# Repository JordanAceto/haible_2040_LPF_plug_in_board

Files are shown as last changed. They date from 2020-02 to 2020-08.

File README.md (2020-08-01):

# NOTE: development of all VCF plug-in boards has been moved here https://github.com/JordanAceto/VCF_plug_in_boards
### This repo will no longer be updated. Follow the above link for the most current files.

# Discrete SSM2040 LPF Plug-In Board 

Small low pass filter PCB, designed to plug into a larger motherboard. This discrete SSM2040 filter implementation is based on notes from the late Jurgen Haible. Thank you for all your wonderful contributions Jurgen.

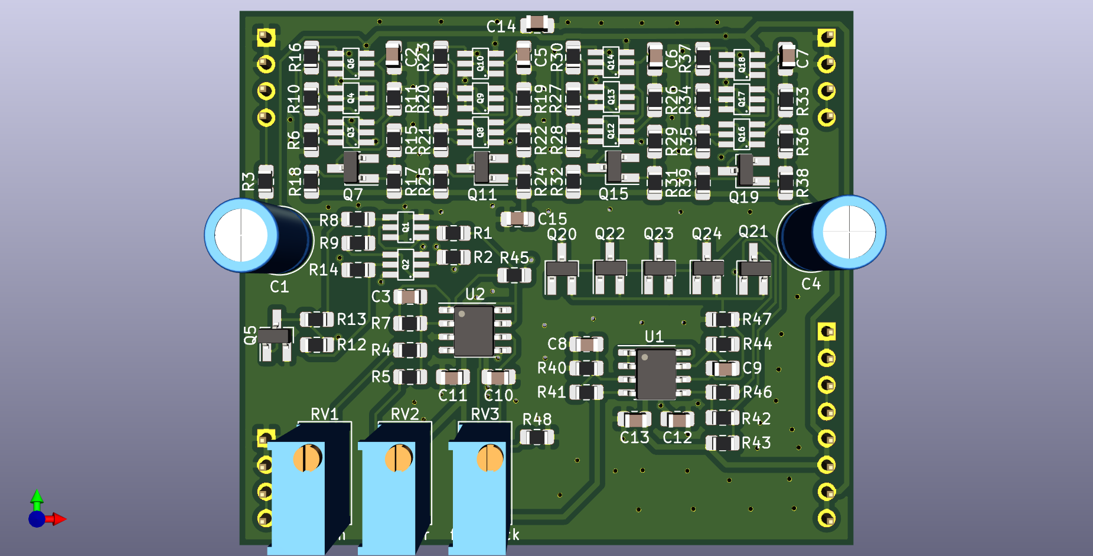
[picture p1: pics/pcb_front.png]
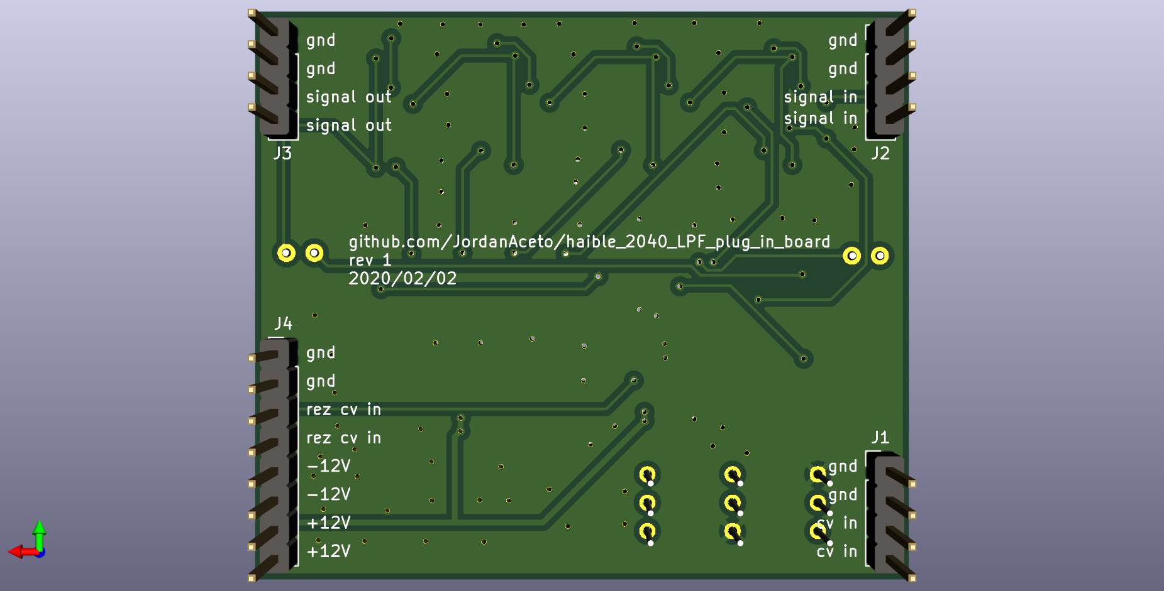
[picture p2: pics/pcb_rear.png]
 

## Details

Four pole LPF with Q compensation. This PCB includes the audio path and CV inputs for frequency and feedback, but does not include any modulation sources.

The intended use for this board is to plug in to a larger motherboard which contains slots for two of these plug-in boards, as well as modulation sources, panel controls, and input/output routing. This motherboard could accept different filter boards sharing this footprint and header layout, for realizing stereo effects of various flavors.

## Inputs

-Audio in: dry audio input to be filtered.

-Frequency CV in: 0 volts to +2.048 volts, higher voltage = higher sweep.

-Feedback CV in: 0 volts to +2.048 volts, higher voltage = more feedback.

## Outputs

-Audio out: filtered audio output.

## Power Supply Requirements

A bipolar 12 volt power supply is required. This will typically come from the motherboard.

## Calibration

-RV1 (depth trim): trims the depth of incoming frequency CV signals. Turn CW for greater depth and CCW for less depth. Adjust to taste.

-RV2 (center trim): trims the center frequency of the filter. Turn CW for higher center frequency and CCW for lower center frequency. Adjust to taste.

-RV3 (feedback trim): trims the maximum amount of feedback. Turn CW for more maximum feedback and CCW for less maximum feedback. Exercise caution when adjusting this, as extreme settings can result in loud oscillations which could damage your ears or speakers if you are monitoring the sound with a loud amplifier. If you set this trimmer to be right on the edge of oscillation when about +2 volts is applied to the feedback CV input then make sure to sweep the frequency through its entire range, as a setting that doesn't squeal at certain frequency settings may squeal at other settings.

## Parts Ordering
The BOM has a link to a Mouser project.

Gerbers can be generated from the kicad_docs.

## License
CC by 4.0

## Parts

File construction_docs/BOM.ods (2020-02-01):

Reference | Quantity | Value | Footprint | Unit Price | Total Price | Product Page
Mouser Parts
C1 C5 | 2 | 10uF | Radial_D6.3mm_H11.0mm_P2.50mm | $0.45 | $0.90 | https://www.mouser.com/ProductDetail/Nichicon/UES1V100MEM
C12 C13 C14 C15 C10 C11 | 6 | 100nF | 0805 | $0.10 | $0.60 | https://www.mouser.com/ProductDetail/KEMET/C0805C104M5RACTU
C2 | 1 | 22uF | 0805 | $0.52 | $0.52 | https://www.mouser.com/ProductDetail/Taiyo-Yuden/TMK212BBJ226MG-TT
C3 | 1 | 470pF | 0805 | $0.14 | $0.14 | https://www.mouser.com/ProductDetail/Yageo/CC0805JRNPO9BN471?qs=sGAEpiMZZMs0AnBnWHyRQMMzfhmH8IQXUBKdtHCIPbI%3D
C4 C7 C8 C9 | 4 | 1nF | 0805 | $0.28 | $1.12 | https://www.mouser.com/ProductDetail/Yageo/CC0805FRNPO9BN102
C6 | 1 | 2n2 | 0805 | $0.27 | $0.27 | https://www.mouser.com/ProductDetail/Yageo/CC0805JKNPO9BN222?qs=sGAEpiMZZMs0AnBnWHyRQMMzfhmH8IQXzJfNxPelwGg%3D
J1 J2 J3 J4 | 1 | breakaway headers | 2.54mm:PinHeader | $2.78 | $2.78 | https://www.mouser.com/ProductDetail/TE-Connectivity/4-103185-0
Q3 Q8 Q12 Q16 Q2 Q1 | 6 | BCM857DS | SOT457 | $0.41 | $2.46 | https://www.mouser.com/ProductDetail/Nexperia/BCM857DS135?qs=sGAEpiMZZMvKM5ialpXrmrzXp%252BgF%2FDi0
Q4 Q6 Q9 Q10 Q13 Q14 Q17 Q18 | 8 | BCM847DS | SOT457 | $0.41 | $3.28 | https://www.mouser.com/ProductDetail/Nexperia/BCM847DS115
Q7 Q23 Q22 Q21 Q20 Q24 Q5 Q11 Q15 Q19 | 10 | BC847 | SOT-23 | $0.13 | $1.30 | https://www.mouser.com/ProductDetail/Nexperia/BC847C215
R16 | 1 | 20k | 0805 | $0.10 | $0.10 | https://www.mouser.com/ProductDetail/Bourns/CR0805-FX-2002ELF
R17 | 1 | 100 | 0805 | $0.10 | $0.10 | https://www.mouser.com/ProductDetail/Bourns/CR0805-FX-1000ELF
R18 R11 R30 R37 R44 | 5 | 120k | 0805 | $0.10 | $0.50 | https://www.mouser.com/ProductDetail/Bourns/CR0805-FX-1203ELF
R19 R12 R31 R28 R38 R35 R45 R42 | 8 | 10k | 0805 | $0.10 | $0.80 | https://www.mouser.com/ProductDetail/Bourns/CR0805-FX-1002ELF
R2 R14 R26 R1 | 4 | 1k | 0805 | $0.10 | $0.40 | https://www.mouser.com/ProductDetail/Bourns/CR0805-FX-1001ELF
R20 | 1 | 180k | 0805 | $0.10 | $0.10 | https://www.mouser.com/ProductDetail/Bourns/CR0805-FX-1803ELF
R21 R15 R10 R32 R39 R46 | 6 | 12k | 0805 | $0.10 | $0.60 | https://www.mouser.com/ProductDetail/Bourns/CR0805-FX-1202ELF
R22 R33 R40 R47 | 4 | 1k2 | 0805 | $0.10 | $0.40 | https://www.mouser.com/ProductDetail/Bourns/CR0805-FX-1201ELF
R23 | 1 | 2k2 | 0805 | $0.10 | $0.10 | https://www.mouser.com/ProductDetail/Bourns/CR0805-FX-2201ELF
R27 R4 | 2 | 100k | 0805 | $0.10 | $0.20 | https://www.mouser.com/ProductDetail/Bourns/CR0805-FX-1003ELF
R3 R24 | 2 | 51k | 0805 | $0.10 | $0.20 | https://www.mouser.com/ProductDetail/Bourns/CR0805-FX-5102ELF
R48 | 1 | 27k | 0805 | $0.10 | $0.10 | https://www.mouser.com/ProductDetail/Bourns/CR0805-FX-2702ELF
R5 R7 | 2 | 560k | 0805 | $0.10 | $0.20 | https://www.mouser.com/ProductDetail/Bourns/CR0805-FX-5603ELF
R6 R13 R25 R29 R34 R36 R41 R43 | 8 | 220 | 0805 | $0.10 | $0.80 | https://www.mouser.com/ProductDetail/Bourns/CR0805-FX-2200ELF
R8 | 1 | 3k3 | 0805 | $0.10 | $0.10 | https://www.mouser.com/ProductDetail/Bourns/CR0805-FX-3301ELF
R9 | 1 | 15k | 0805 | $0.10 | $0.10 | https://www.mouser.com/ProductDetail/Bourns/CR0805-FX-1502ELF
RV1 | 1 | 10k | Bourns_3269W | $4.83 | $4.83 | https://www.mouser.com/ProductDetail/Bourns/3269W-1-103LF?qs=sGAEpiMZZMvygUB3GLcD7lKKmqkeksZmGot4dXELruo%3D
RV2 RV3 | 2 | 100k | Bourns_3269W | $4.83 | $9.66 | https://www.mouser.com/ProductDetail/Bourns/3269W-1-104LF?qs=sGAEpiMZZMvygUB3GLcD7iPUMwpiXMBsQtXtzdbyTwg%3D
U1 U2 | 2 | TL072 | SOIC-8 | $0.59 | $1.18 | https://www.mouser.com/ProductDetail/Texas-Instruments/TL072CDR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
 |  |  | Total |  | $33.84
 |  |  | Link to Mouser project |  |  | https://www.mouser.com/ProjectManager/ProjectDetail.aspx?AccessID=2b5f0e1beb

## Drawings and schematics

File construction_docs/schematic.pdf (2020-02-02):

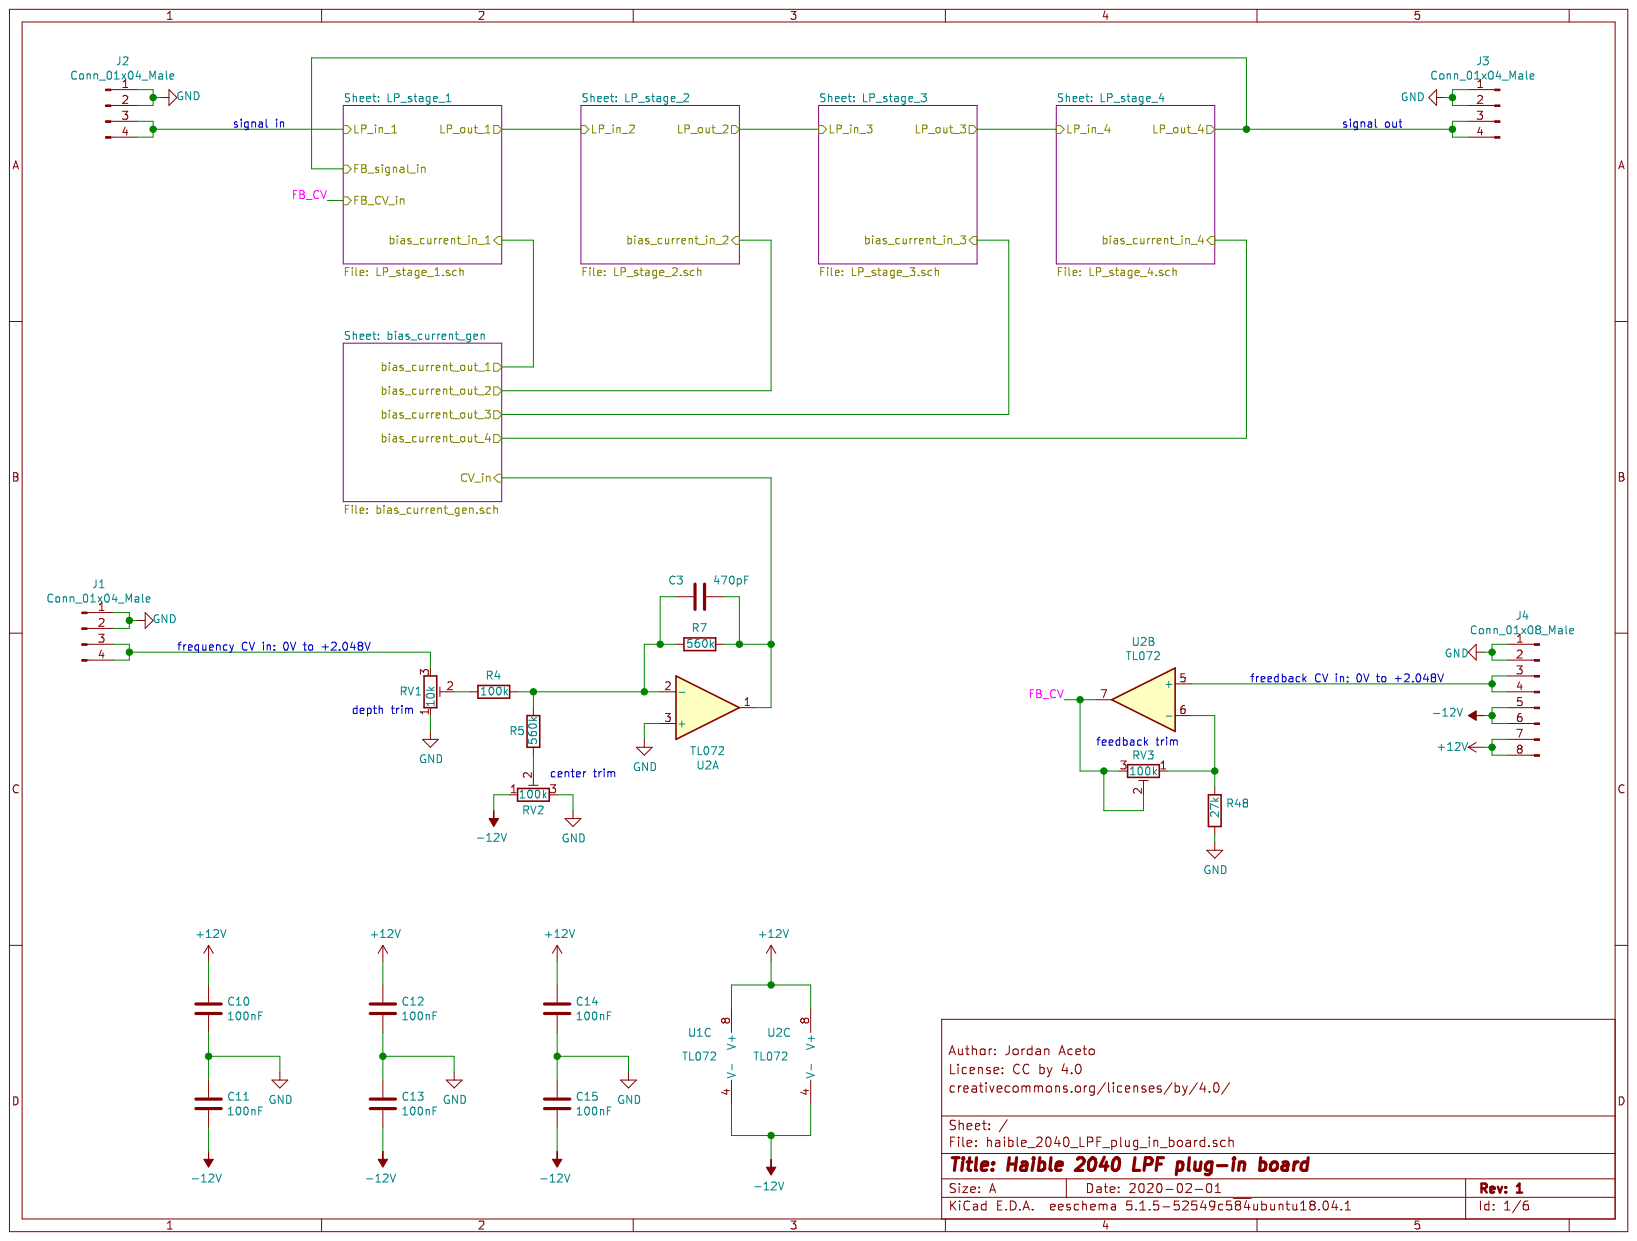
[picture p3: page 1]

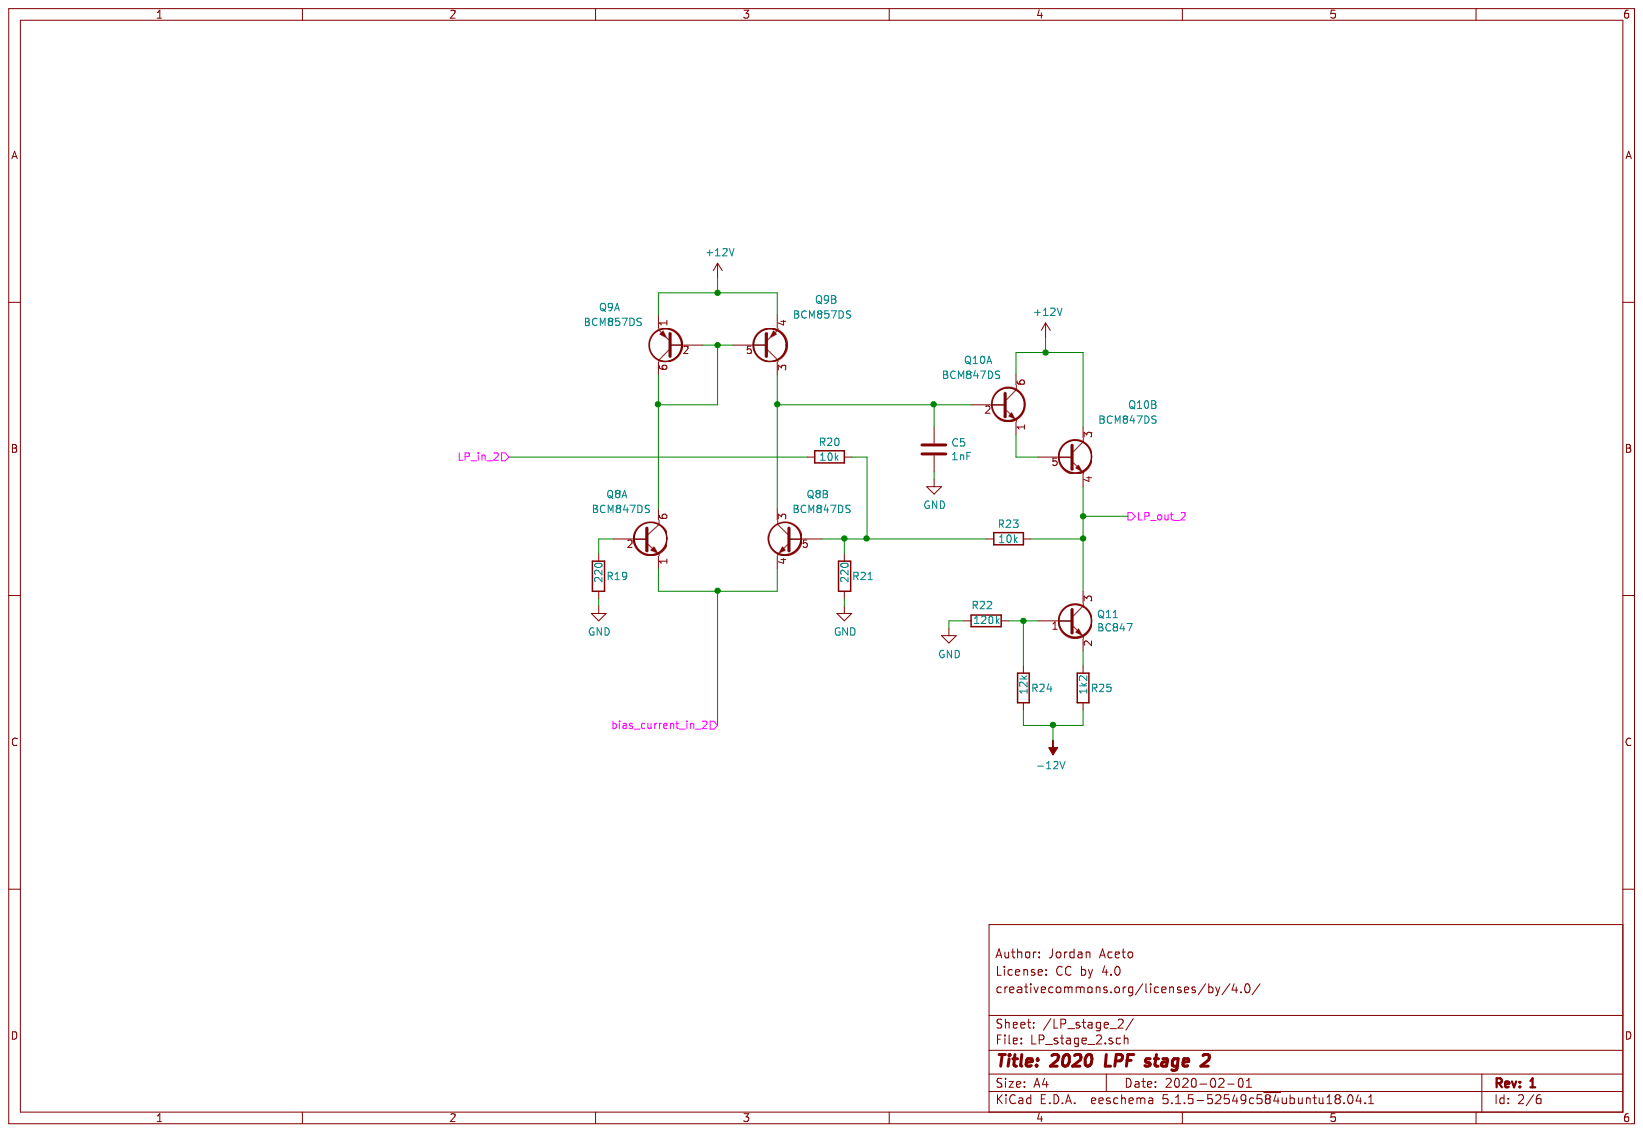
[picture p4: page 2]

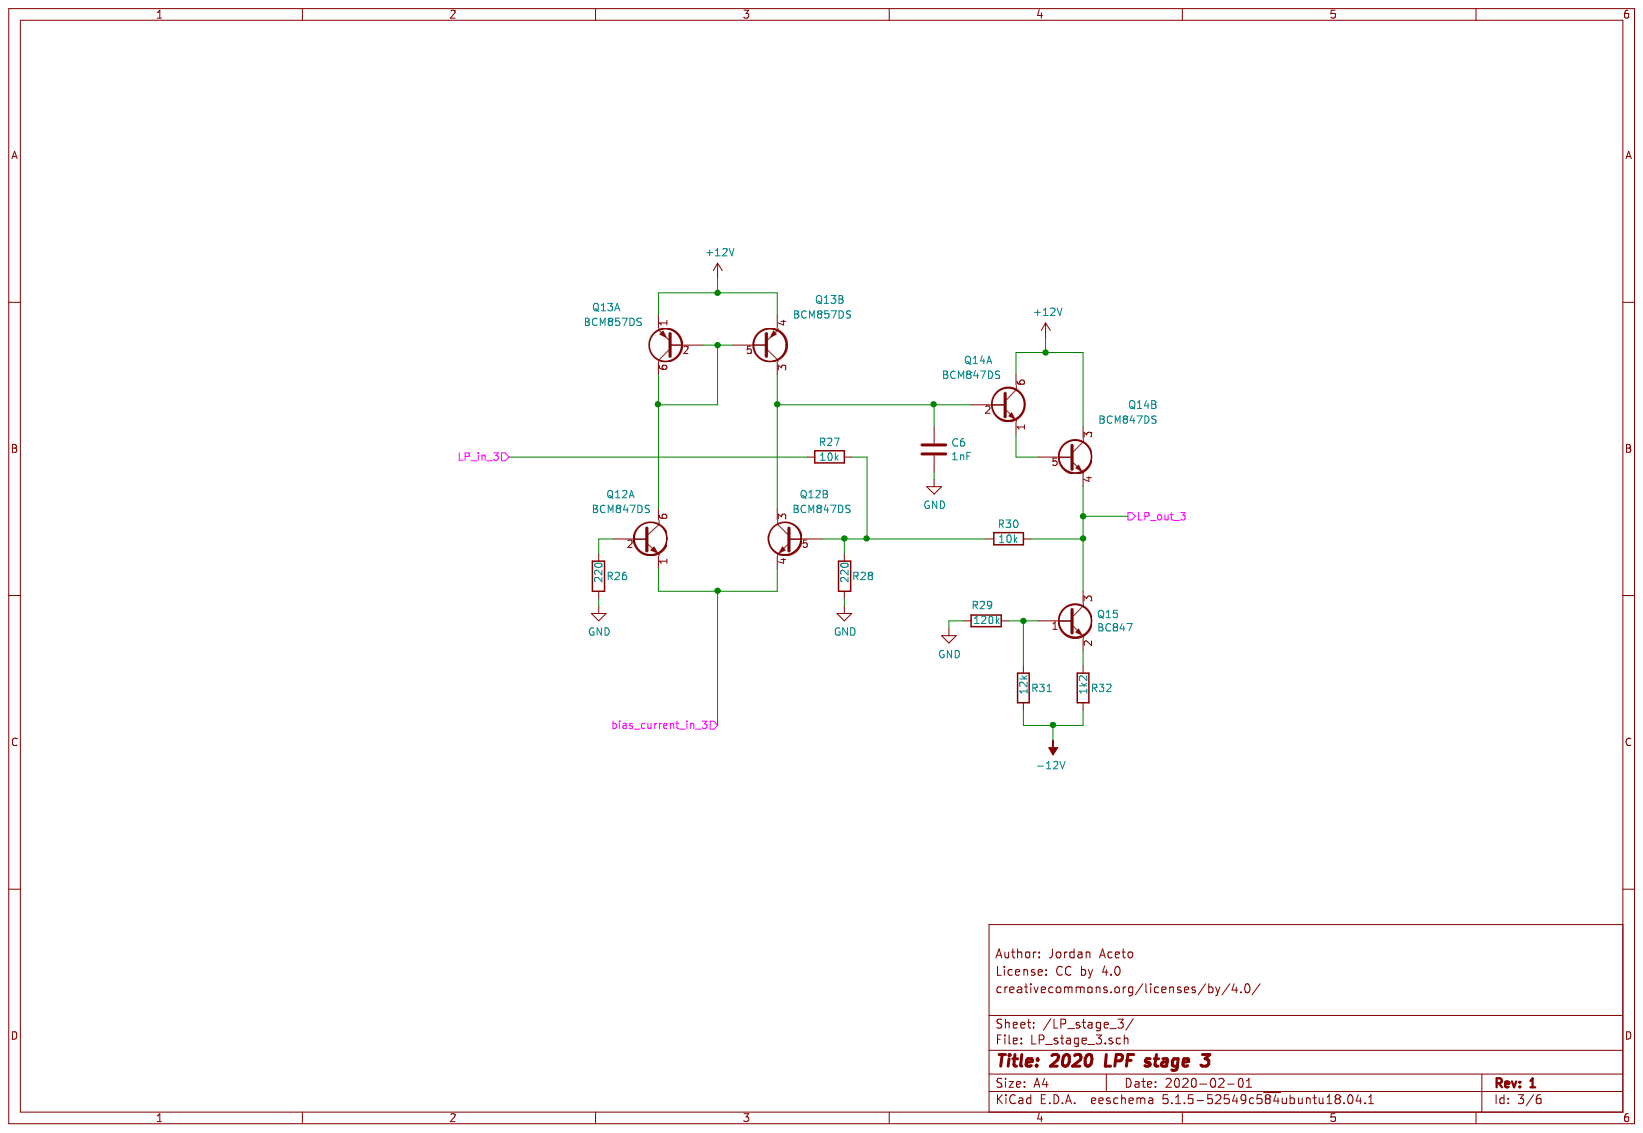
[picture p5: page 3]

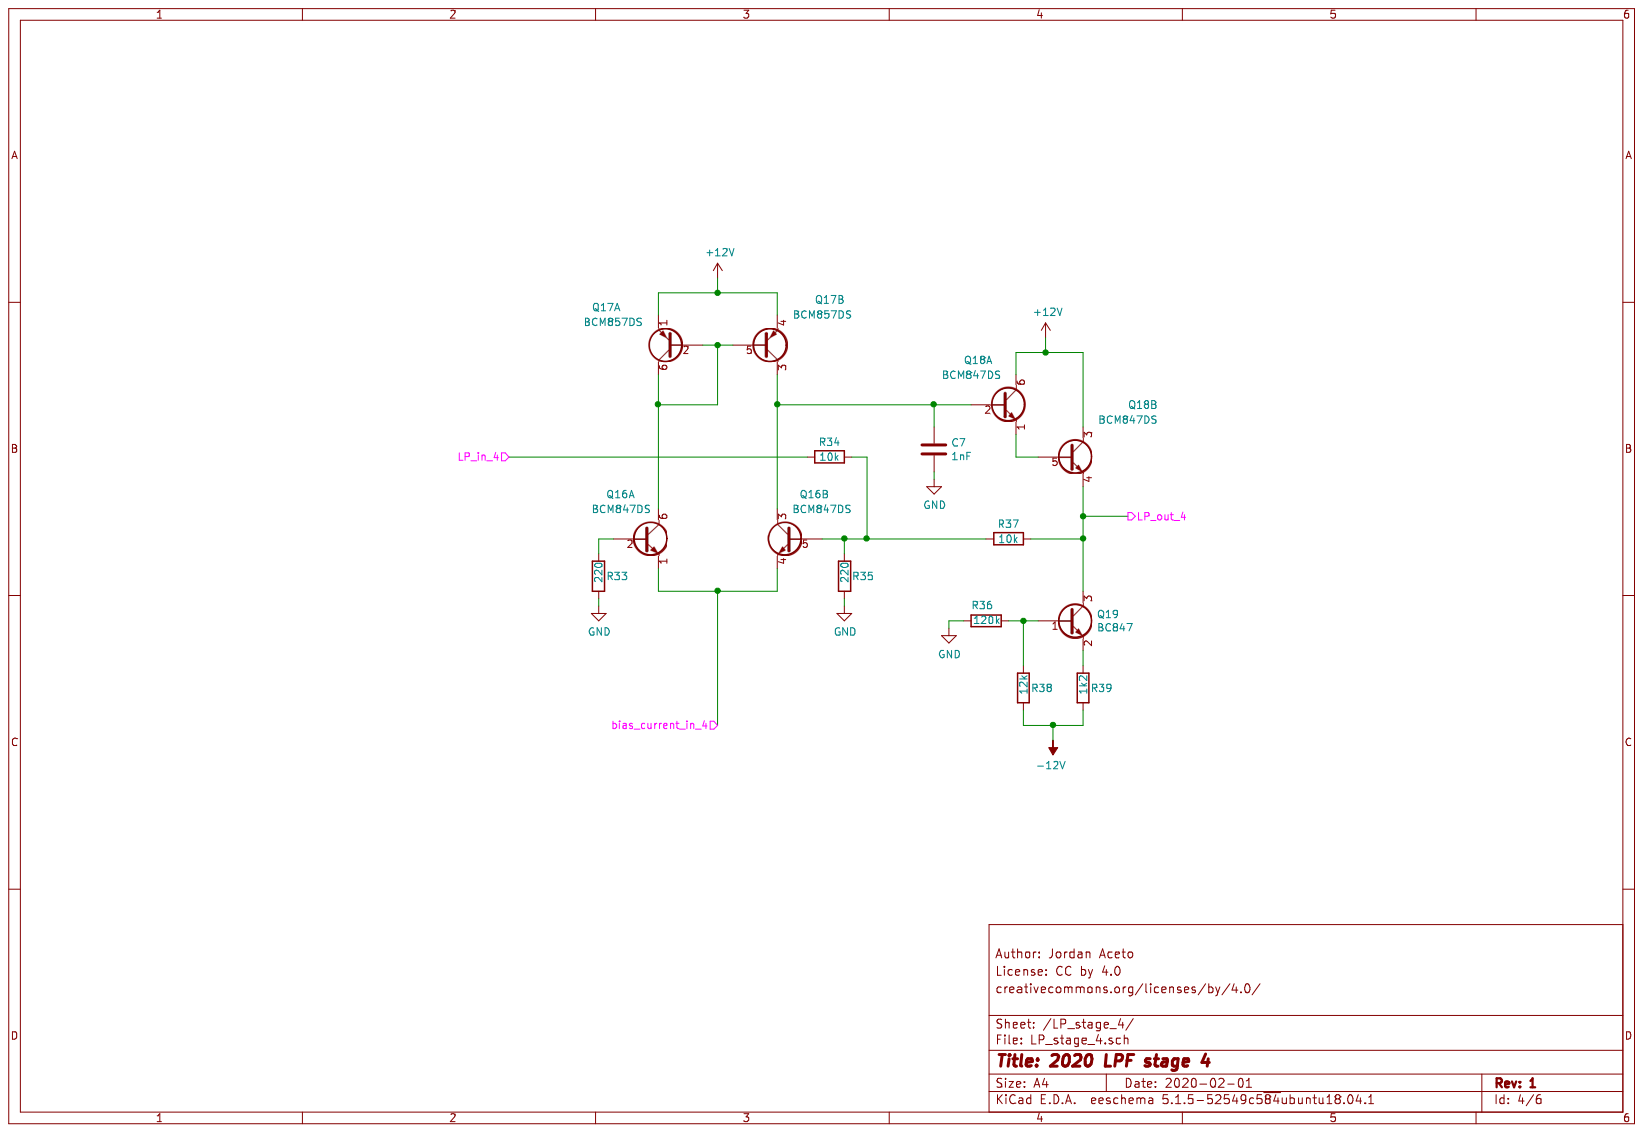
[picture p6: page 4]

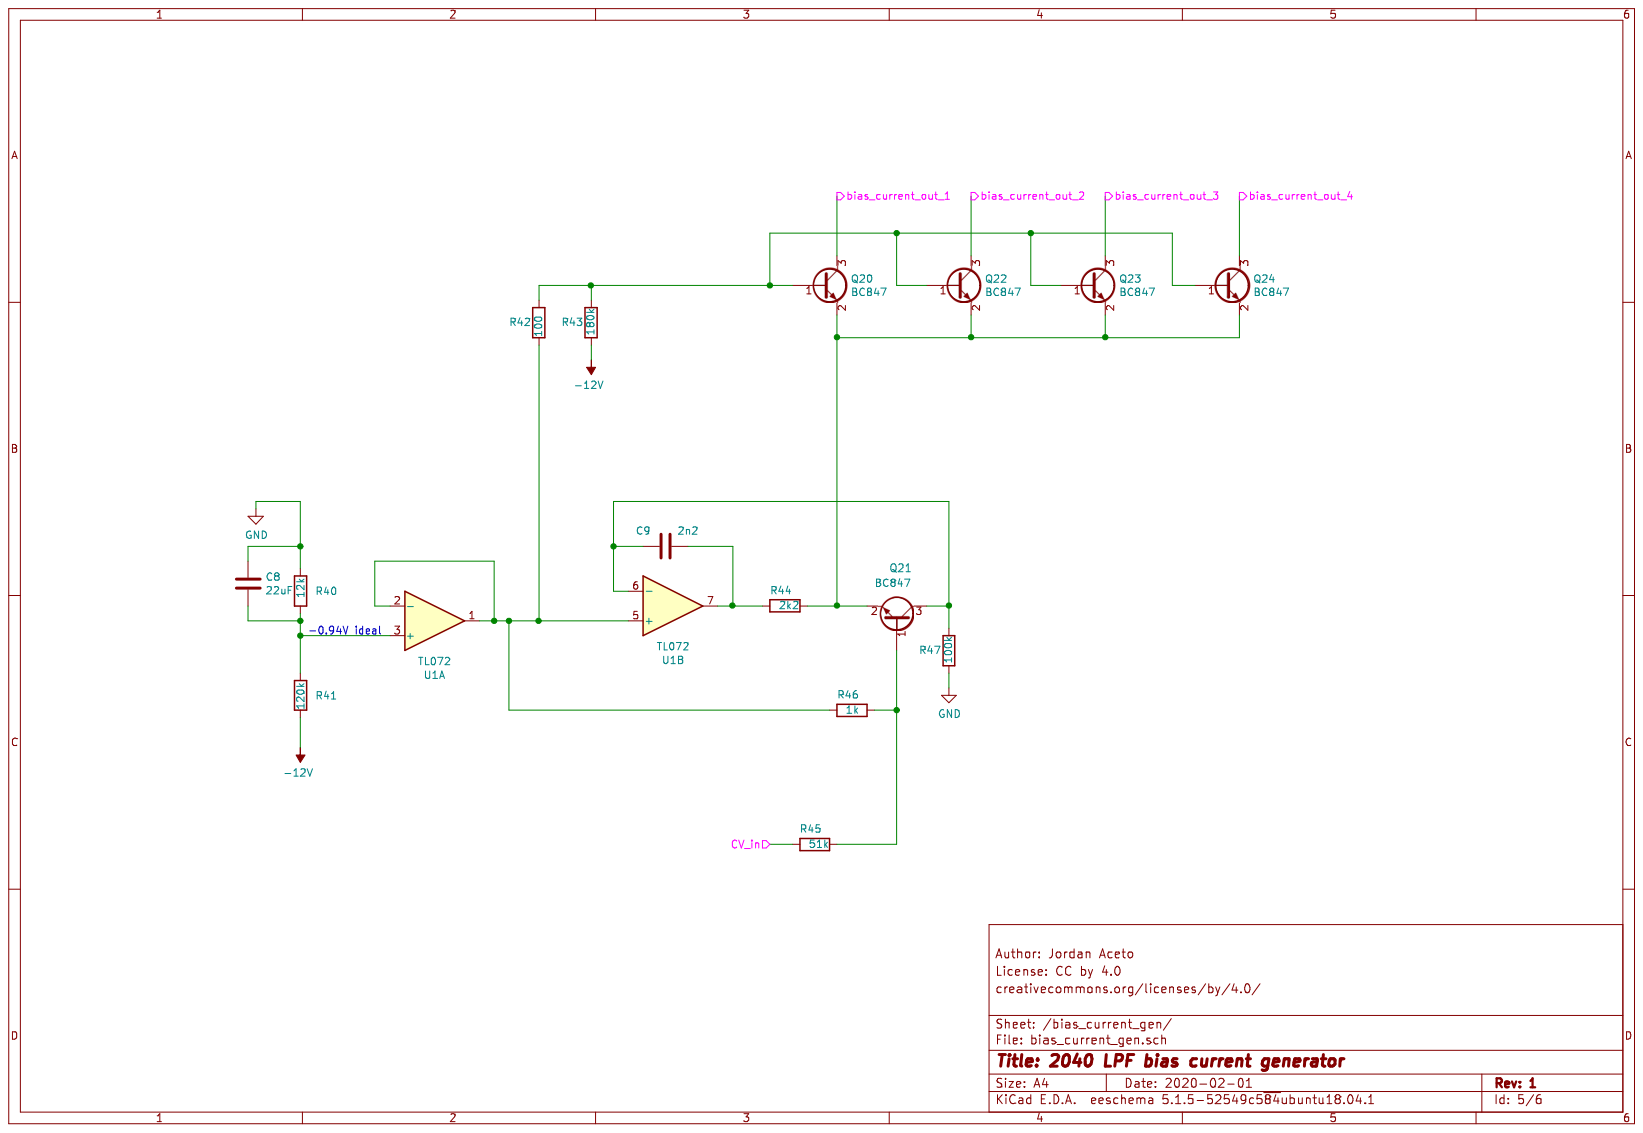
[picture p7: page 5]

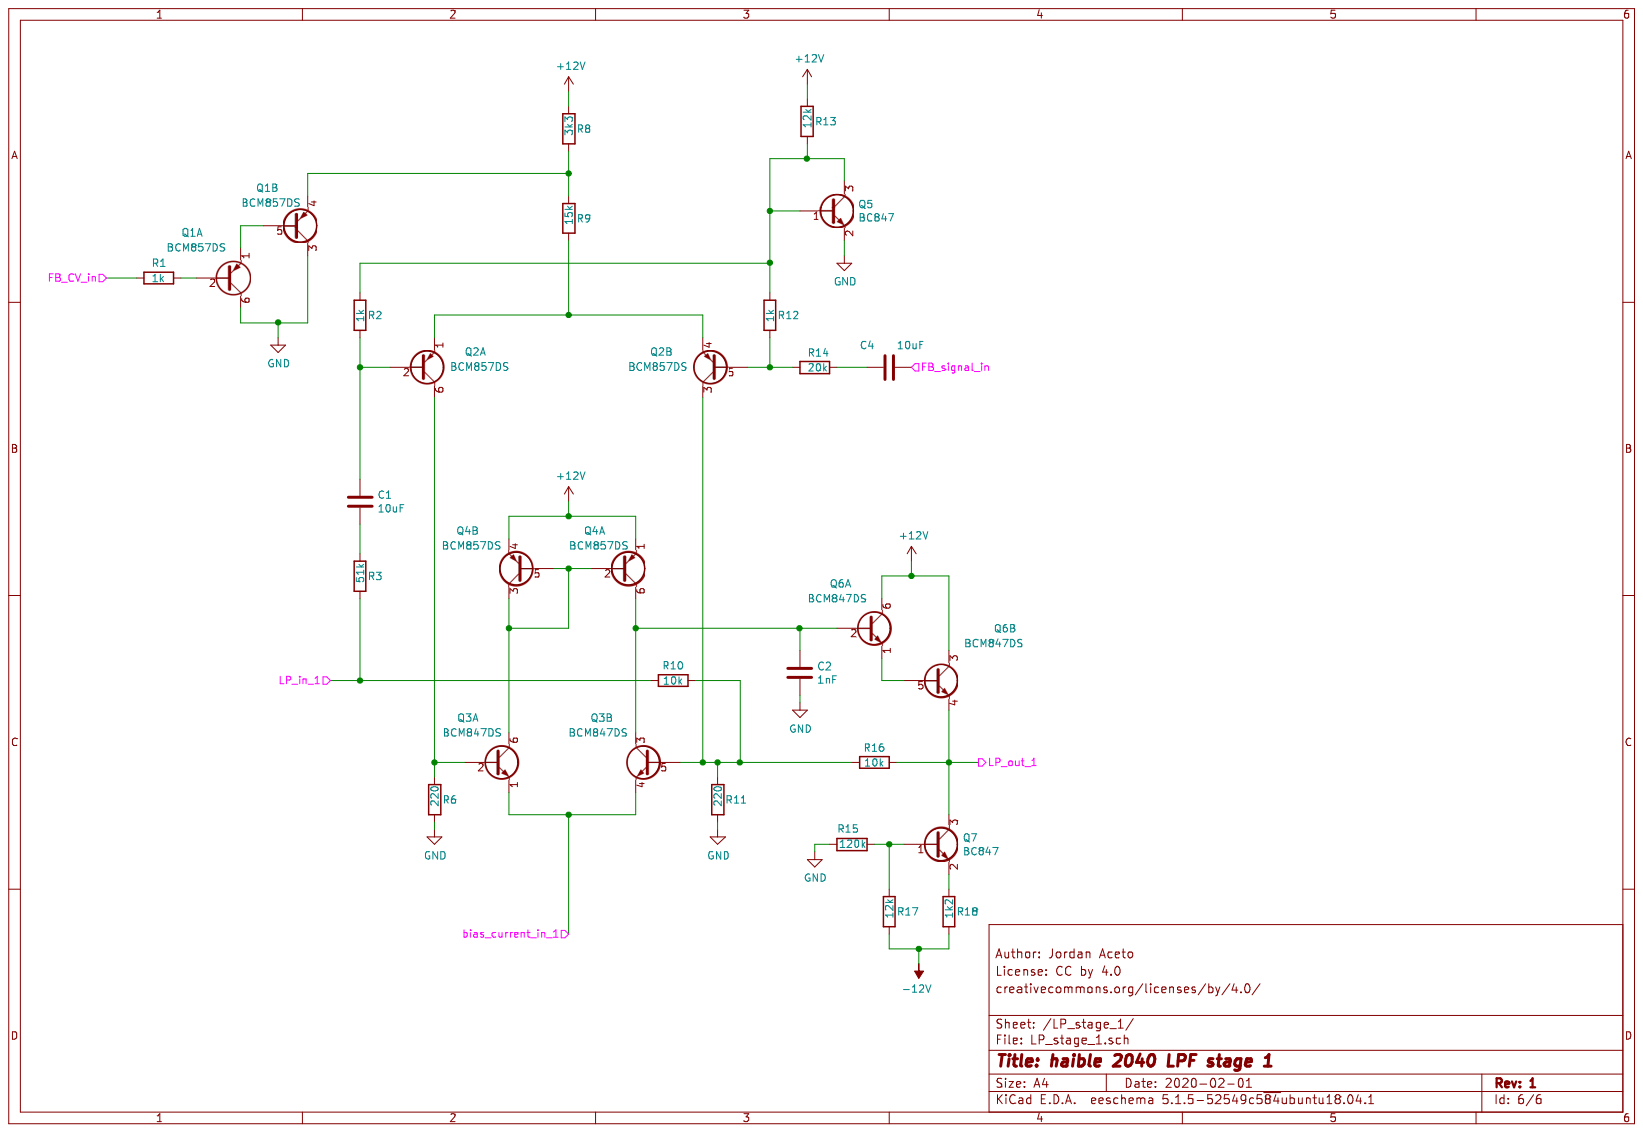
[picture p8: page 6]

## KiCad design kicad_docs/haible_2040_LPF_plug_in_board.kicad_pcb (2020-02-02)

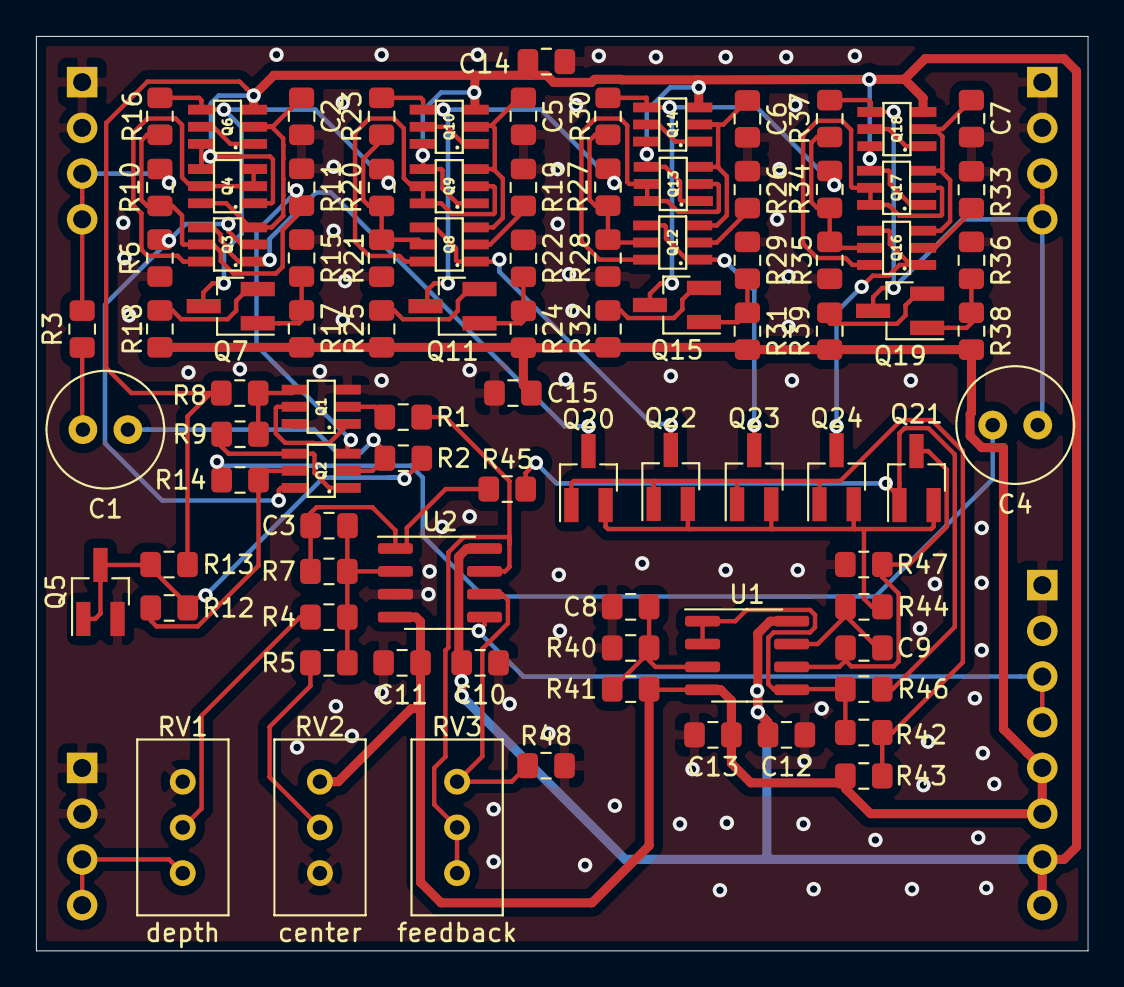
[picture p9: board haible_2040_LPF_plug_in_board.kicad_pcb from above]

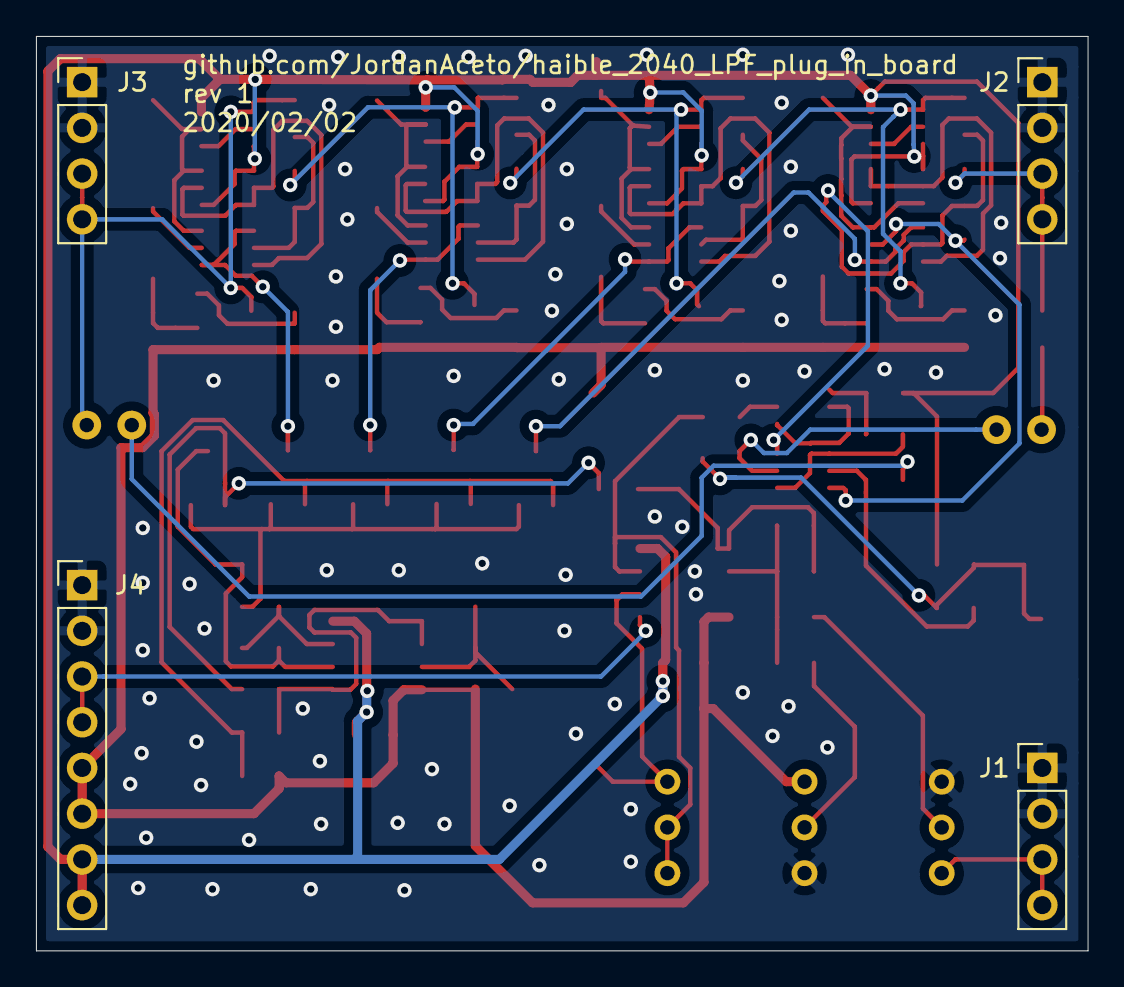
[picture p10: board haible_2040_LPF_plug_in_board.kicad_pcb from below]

Board: 2 copper layers, 58.4 x 50.8 mm, 96 parts (4 on the bottom side), 64 nets.

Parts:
C1, C4: 10uF; C_Radial_D6.3mm_H11.0mm_P2.50mm
C2, C5, C6, C7: 1nF; C_0805_2012Metric_Pad1.15x1.40mm_HandSolder
C3: 470pF; C_0805_2012Metric_Pad1.15x1.40mm_HandSolder
C8: 22uF; C_0805_2012Metric_Pad1.15x1.40mm_HandSolder
C9: 2n2; C_0805_2012Metric_Pad1.15x1.40mm_HandSolder
C10, C11, C12, C13, C14, C15: 100nF; C_0805_2012Metric_Pad1.15x1.40mm_HandSolder
J1, J2, J3: Conn_01x04_Male; PinHeader_1x04_P2.54mm_Vertical
J4: Conn_01x08_Male; PinHeader_1x08_P2.54mm_Vertical
Q1, Q2, Q4, Q9, Q13, Q17: BCM857DS; SOT457
Q3, Q6, Q8, Q10, Q12, Q14, Q16, Q18: BCM847DS; SOT457
Q5, Q7, Q11, Q15, Q19, Q20, Q21, Q22, Q23, Q24: BC847; SOT-23_Handsoldering
R1, R2, R12, R46: 1k; R_0805_2012Metric_Pad1.15x1.40mm_HandSolder
R3, R45: 51k; R_0805_2012Metric_Pad1.15x1.40mm_HandSolder
R4, R47: 100k; R_0805_2012Metric_Pad1.15x1.40mm_HandSolder
R5, R7: 560k; R_0805_2012Metric_Pad1.15x1.40mm_HandSolder
R6, R11, R19, R21, R26, R28, R33, R35: 220; R_0805_2012Metric_Pad1.15x1.40mm_HandSolder
R8: 3k3; R_0805_2012Metric_Pad1.15x1.40mm_HandSolder
R9: 15k; R_0805_2012Metric_Pad1.15x1.40mm_HandSolder
R10, R16, R20, R23, R27, R30, R34, R37: 10k; R_0805_2012Metric_Pad1.15x1.40mm_HandSolder
R13, R17, R24, R31, R38, R40: 12k; R_0805_2012Metric_Pad1.15x1.40mm_HandSolder
R14: 20k; R_0805_2012Metric_Pad1.15x1.40mm_HandSolder
R15, R22, R29, R36, R41: 120k; R_0805_2012Metric_Pad1.15x1.40mm_HandSolder
R18, R25, R32, R39: 1k2; R_0805_2012Metric_Pad1.15x1.40mm_HandSolder
R42: 100; R_0805_2012Metric_Pad1.15x1.40mm_HandSolder
R43: 180k; R_0805_2012Metric_Pad1.15x1.40mm_HandSolder
R44: 2k2; R_0805_2012Metric_Pad1.15x1.40mm_HandSolder
R48: 27k; R_0805_2012Metric_Pad1.15x1.40mm_HandSolder
RV1: 10k; Potentiometer_Bourns_3296W_Vertical
RV2, RV3: 100k; Potentiometer_Bourns_3296W_Vertical
U1, U2: TL072; SOIC-8_3.9x4.9mm_P1.27mm

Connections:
+12V: C10.1, C12.1, C14.1, J4.7, J4.8, Q4.1, Q4.4, Q6.3, Q6.6, Q9.1, Q9.4, Q10.3, Q10.6, Q13.1, Q13.4, Q14.3, Q14.6, Q17.1, Q17.4, Q18.3, Q18.6, R8.1, R13.1, U1.8, U2.8
-12V: C11.2, C13.2, C15.2, J4.5, J4.6, R17.2, R18.2, R24.2, R25.2, R31.2, R32.2, R38.2, R39.2, R41.2, R43.1, RV2.1, U1.4, U2.4
/FB_CV: R1.2, RV3.2, RV3.3, U2.7
/LP_stage_1/FB_signal_in: C4.1, J3.3, J3.4, Q18.4, Q19.3, R37.1
/LP_stage_1/LP_in_1: J2.3, J2.4, R3.2, R10.2
/LP_stage_1/bias_current_in_1: Q3.1, Q3.4, Q20.3
/LP_stage_2/LP_in_2: Q6.4, Q7.3, R16.1, R20.2
/LP_stage_2/bias_current_in_2: Q8.1, Q8.4, Q22.3
/LP_stage_3/LP_in_3: Q10.4, Q11.3, R23.1, R27.2
/LP_stage_3/bias_current_in_3: Q12.1, Q12.4, Q23.3
/LP_stage_4/LP_in_4: Q14.4, Q15.3, R30.1, R34.2
/LP_stage_4/bias_current_in_4: Q16.1, Q16.4, Q24.3
/bias_current_gen/CV_in: C3.2, R7.2, R45.1, U2.1
GND: C2.2, C5.2, C6.2, C7.2, C8.1, C10.2, C11.1, C12.2, C13.1, C14.2, C15.1, J1.1, J1.2, J2.1, J2.2, J3.1, J3.2, J4.1, J4.2, Q1.3, Q1.6, Q5.2, R6.2, R11.2, R15.1, R19.2, R21.2, R22.1, R26.2, R28.2, R29.1, R33.2, R35.2, R36.1, R40.1, R47.1, R48.2, RV1.1, RV2.3, U2.3
unnamed: C1.1, Q2.2, R2.2
unnamed: C1.2, R3.1
unnamed: C2.1, Q3.3, Q4.6, Q6.2
unnamed: C3.1, R4.2, R5.2, R7.1, U2.2
unnamed: C4.2, R14.1
unnamed: C5.1, Q8.3, Q9.3, Q10.2
unnamed: C6.1, Q12.3, Q13.3, Q14.2
unnamed: C7.1, Q16.3, Q17.3, Q18.2
unnamed: C8.2, R40.2, R41.1, U1.3
unnamed: C9.1, Q21.3, R47.2, U1.6
unnamed: C9.2, R44.1, U1.7
unnamed: J1.3, J1.4, RV1.3
unnamed: J4.3, J4.4, U2.5
unnamed: Q1.1, Q1.5
unnamed: Q1.2, R1.1
unnamed: Q1.4, R8.2, R9.1
unnamed: Q2.1, Q2.4, R9.2
unnamed: Q2.3, Q3.5, R10.1, R11.1, R16.2
unnamed: Q2.5, R12.2, R14.2
unnamed: Q2.6, Q3.2, R6.1
unnamed: Q3.6, Q4.2, Q4.3, Q4.5
unnamed: Q5.1, Q5.3, R2.1, R12.1, R13.2
unnamed: Q6.1, Q6.5
unnamed: Q7.1, R15.2, R17.1
unnamed: Q7.2, R18.1
unnamed: Q8.2, R19.1
unnamed: Q8.5, R20.1, R21.1, R23.2
unnamed: Q8.6, Q9.2, Q9.5, Q9.6
unnamed: Q10.1, Q10.5
unnamed: Q11.1, R22.2, R24.1
unnamed: Q11.2, R25.1
unnamed: Q12.2, R26.1
unnamed: Q12.5, R27.1, R28.1, R30.2
unnamed: Q12.6, Q13.2, Q13.5, Q13.6
unnamed: Q14.1, Q14.5
unnamed: Q15.1, R29.2, R31.1
unnamed: Q15.2, R32.1
unnamed: Q16.2, R33.1
unnamed: Q16.5, R34.1, R35.1, R37.2
unnamed: Q16.6, Q17.2, Q17.5, Q17.6
unnamed: Q18.1, Q18.5
unnamed: Q19.1, R36.2, R38.1
unnamed: Q19.2, R39.1
unnamed: Q20.1, Q22.1, Q23.1, Q24.1, R42.2, R43.2
unnamed: Q20.2, Q21.2, Q22.2, Q23.2, Q24.2, R44.2
unnamed: Q21.1, R45.2, R46.2
unnamed: R4.1, RV1.2
unnamed: R5.1, RV2.2
unnamed: R42.1, R46.1, U1.1, U1.2, U1.5
unnamed: R48.1, RV3.1, U2.6

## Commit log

2020-02-02 split schem into pages, redo pcb
    [LP_stage_1.sch, LP_stage_2.sch, LP_stage_3.sch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]
2020-02-02 add schematic pdf
2020-02-02 tidy up pcb
    [haible_2040_LPF_plug_in_board.kicad_pcb]
2020-02-02 fix rear pcb view pic

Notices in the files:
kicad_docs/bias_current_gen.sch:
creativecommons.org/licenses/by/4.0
